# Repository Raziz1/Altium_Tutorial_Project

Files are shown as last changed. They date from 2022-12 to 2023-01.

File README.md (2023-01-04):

# Altium_Tutorial_Project ⚡🖥️
The following files were completed as a part of the Altium free PCB design course. Project A - A Power Regulator and LED Board. The PCB design course can be found at the following link below
* [Altium Education Courses](https://education.altium.com/)

This project goes over all the material covered in this course which includes
* Schematics & Libraries
* PCB Layout
* Routing & Basic Signal Integrity
* PCB Manufacturing

## Functional Requirements



The primary goal of this project was to design a power regulator shield board for the Arduino Uno that powers a bank of LEDs as well as the Arduino Uno. The design of the board had to meet the following set of requirements:

1. Receive power from a 12 V DC input
2. Regulate power down to 5 V DC
3. Deliver 12 V DC power to a bank of 2 LED lights in parallel
4. Provide 5 V DC power to the main Arduino Uno board
5. Provide enough current to power the Arduino and the LEDs
6. Regulate power with at least 90% efficiency
7. LEDs must be SMD parts with high power output (at least 10 W each)
8. Power input connection is provided by standard 16 AWG wire
9. Components must be placed only on the top layer
10. Total board thickness must be standard thickness (approximately 62 mils)

When designing the board shape I referenced the Arduino.cc website [See this link](https://store-usa.arduino.cc/products/arduino-uno-rev3/?selectedStore=us)

## Creating the schematics
When designing the schematics there were a couple components that required external libraries.

| **Part number**  | **Quantity** | **Description** | **Where To Find** |
| --- |:---:|:---:|:---:|
| SSQ-108-03-T-S| 2 | 8-pin header | [Link](https://www.samtec.com/products/ssq-108-03-t-s)| 
| SSQ-106-03-T-S| 1 | 6-pin header | [Link](https://www.samtec.com/products/ssq-106-03-t-s)| 
| SSQ-110-03-T-S| 1 | 10-pin header | [Link](https://www.samtec.com/products/ssq-110-03-t-s)| 

The rest of the parts including the LEDs (MKRAWT-00-0000-0D0HG235H) can be directly placed from the manufacturer's part search.

The power regulator design was made using the [WeBench platform](https://webench.ti.com/power-designer/) with the following requirements:
* Vin Min: 12 V 
* Vin Max: 12 V 
* Vout: 5 V 
* Iout Max: 1 A

This project used the TPS562200 regulator design.

## PCB layout
Details related to the PCB layout & Stackup layout can be found in the output files above

## Output files
The following output files were included
* Bill of Materials
* Gerber
* NC Drill 
* Pick-and-place
* Board Stackup
* Drill Drawing/Guides
* Schematic Prints
* PCB prints

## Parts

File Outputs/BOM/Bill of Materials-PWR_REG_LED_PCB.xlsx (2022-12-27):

Comment | Description | Designator | Footprint | LibRef | Quantity
CC0805KRX7R8BB104 | CAP CER 0.1UF 25V X7R 0805 | Cbst, Cin1, Cin2, Cout1, Cout2 | FP-CC0805-0_85-MFG | CMP-1036-04410-2 | 5
MKRAWT-00-0000-0D0HG235H | LED, White, 12 V, 2-Pin SMD, RoHS, Tape and Reel | D1, D2 | CREE-MK-R-2_V | CMP-2100-00977-1 | 2
8-Pin-Header | 8 Position Receptacle Connector Through Hole, Right Angle | J1, J4 | SAMTEC_SSQ-108-03-X-S | SSQ-108-03-X-S | 2
1x6 Header | 6 Position Receptacle Connector Through Hole | J2 | SAMTEC_SSQ-106-03-X-S | SSQ-106-03-X-S | 1
10-Pin-Header | 10 Position Receptacle Connector Through Hole, Right Angle | J3 | SAMTEC_SSQ-110-03-X-S | SSQ-110-03-X-S | 1
NRS8030T3R3MJGJ | Inductor Power Shielded Wirewound 3.3uH 20% 100KHz Ferrite 4.2A 24.7mΩ DCR T/R | L1 | FP-NRS8030-MFG | CMP-14484-000405-1 | 1
ERJ2RKF1002X | Chip Resistor, 10 KOhm, +/- 1%, 0.1 W, -55 to 155 degC, 0402 (1005 Metric), RoHS, Tape and Reel | Rfbb | RESC1005X40X25LL05T05 | CMP-2000-07588-1 | 1
CRCW020156K2FNED |  | Rfbt | RESC0603X28X15NL05T05 | CMP-2004-00723-1 | 1
TPS562201DDCR | IC REG BUCK ADJ 2A TSOT23-6 | U1 | FP-DDC0006A-IPC_C | CMP-04918-000361-1 | 1

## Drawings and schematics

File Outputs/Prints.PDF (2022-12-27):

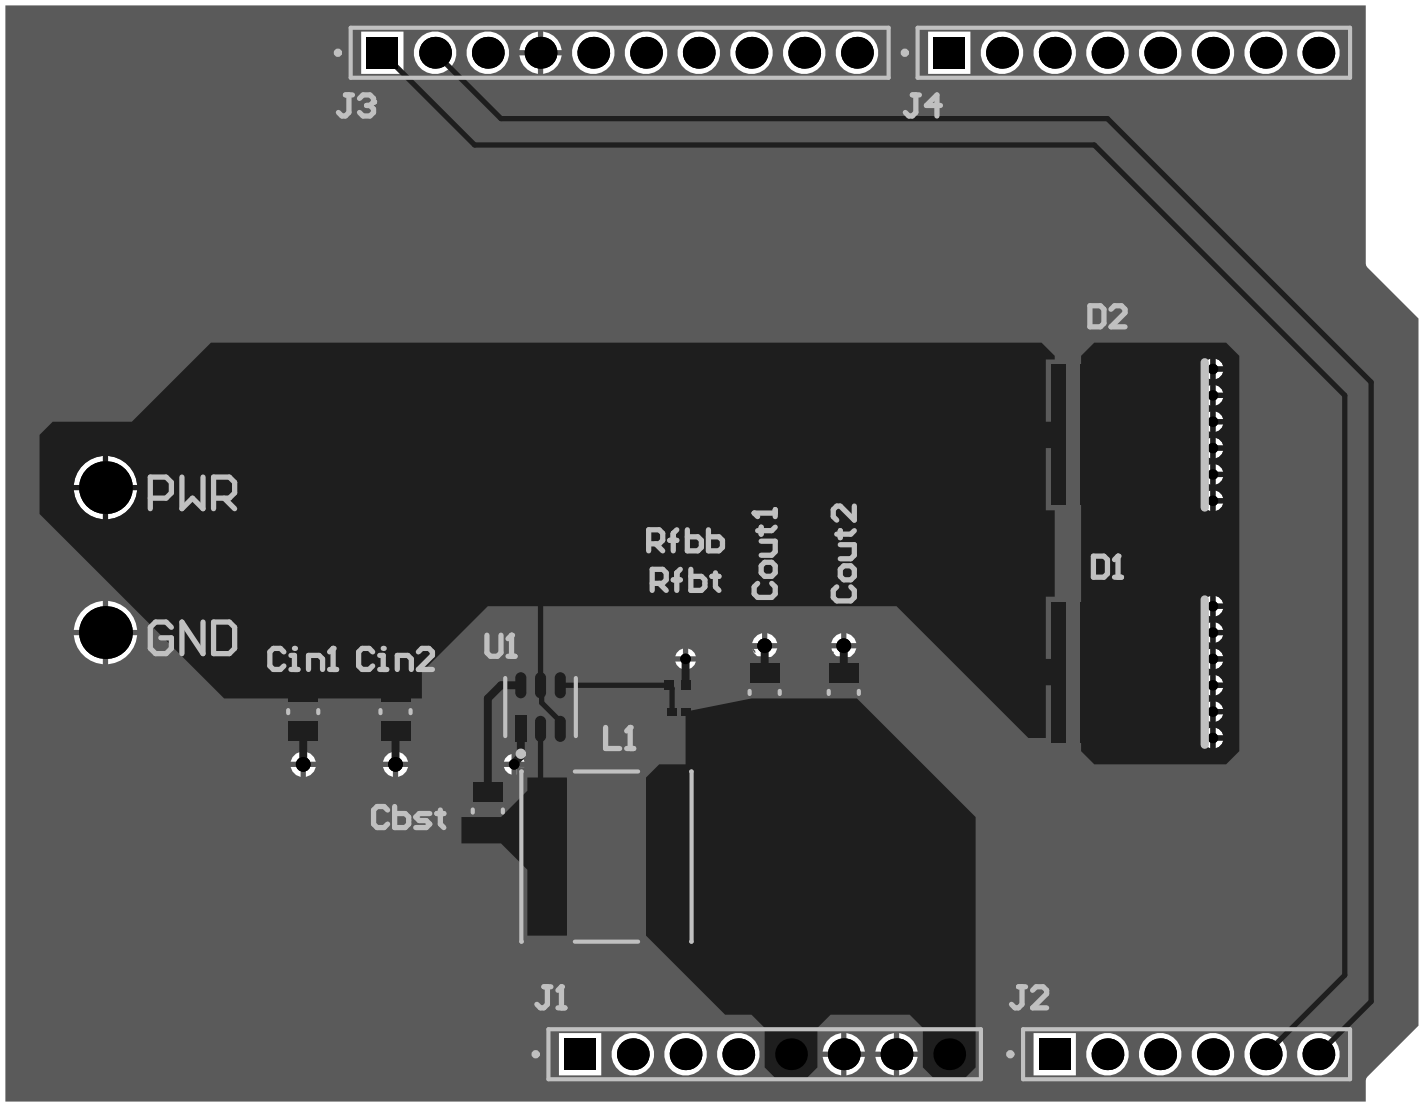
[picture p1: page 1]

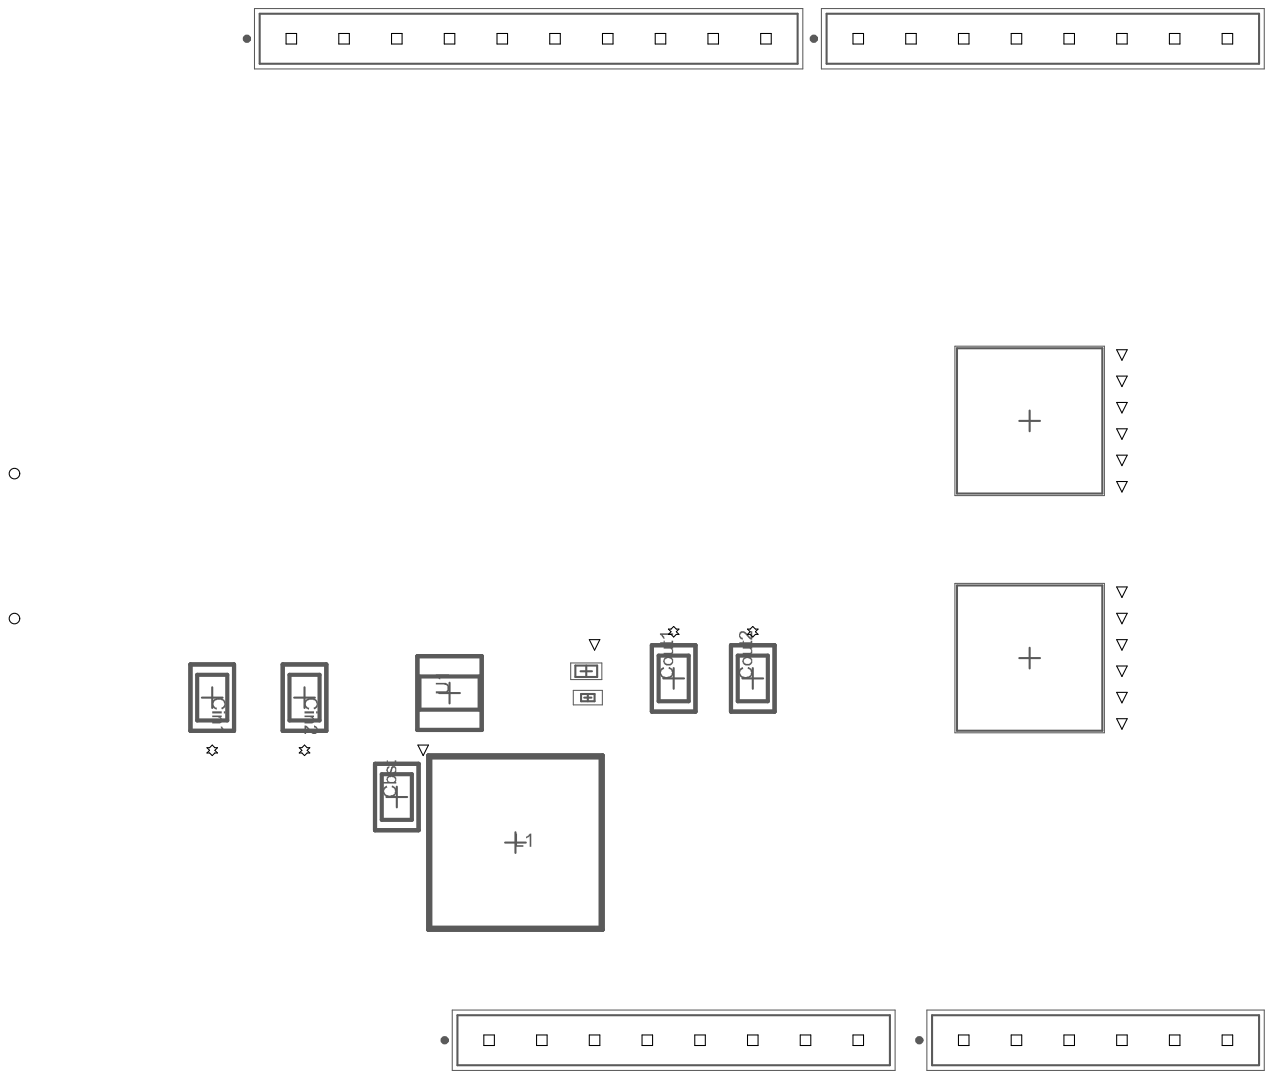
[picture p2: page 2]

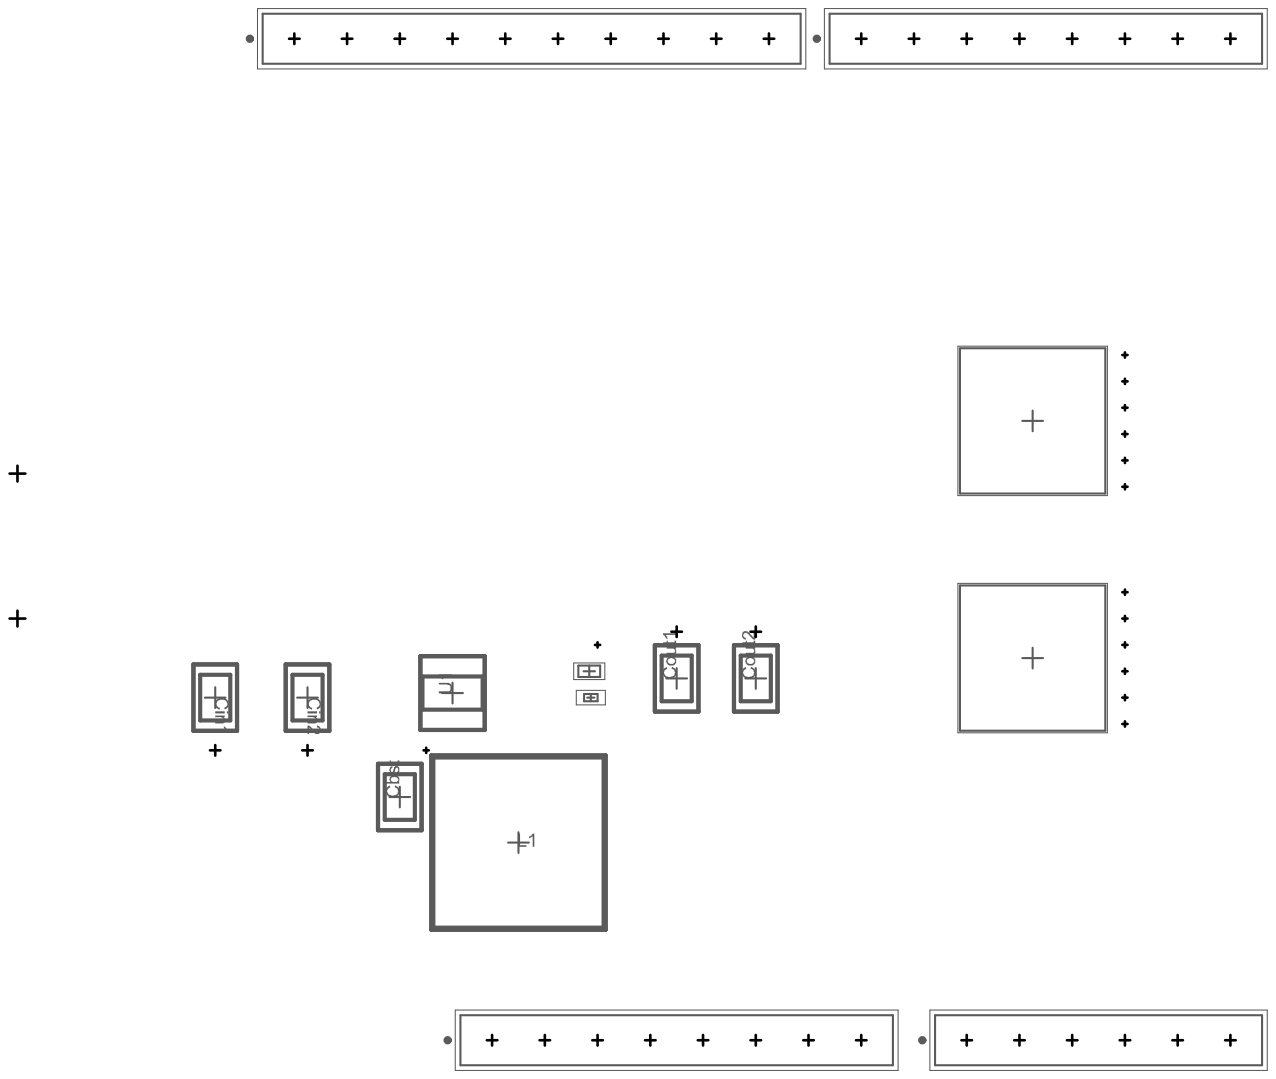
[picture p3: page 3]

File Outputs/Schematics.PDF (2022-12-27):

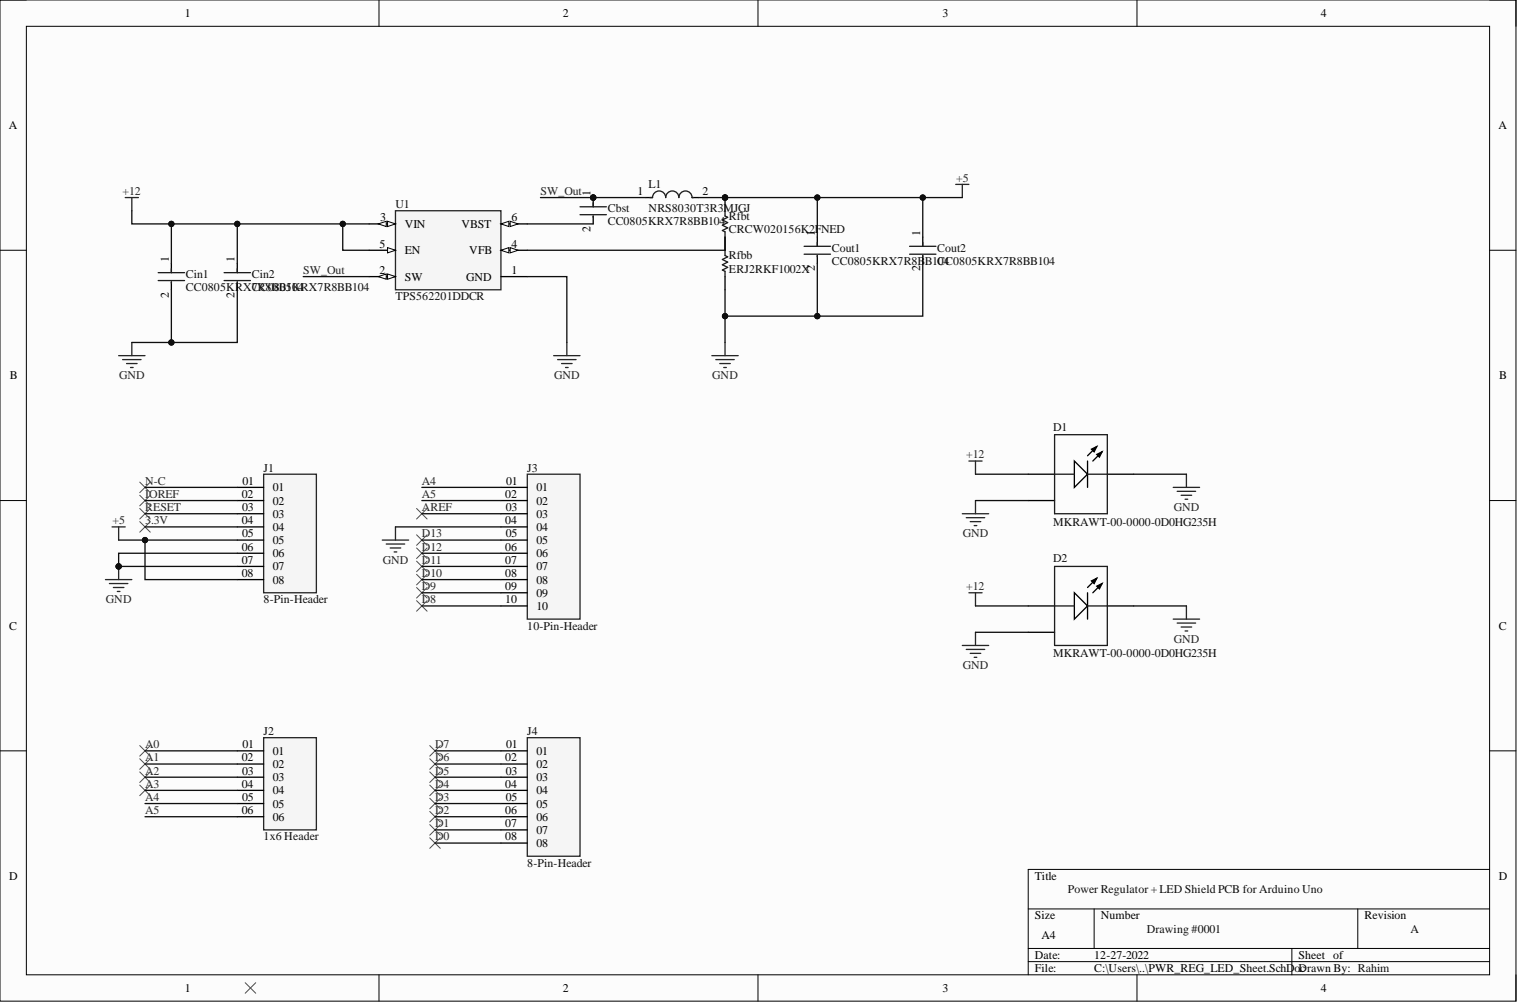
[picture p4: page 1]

0 6
0 7
0 8

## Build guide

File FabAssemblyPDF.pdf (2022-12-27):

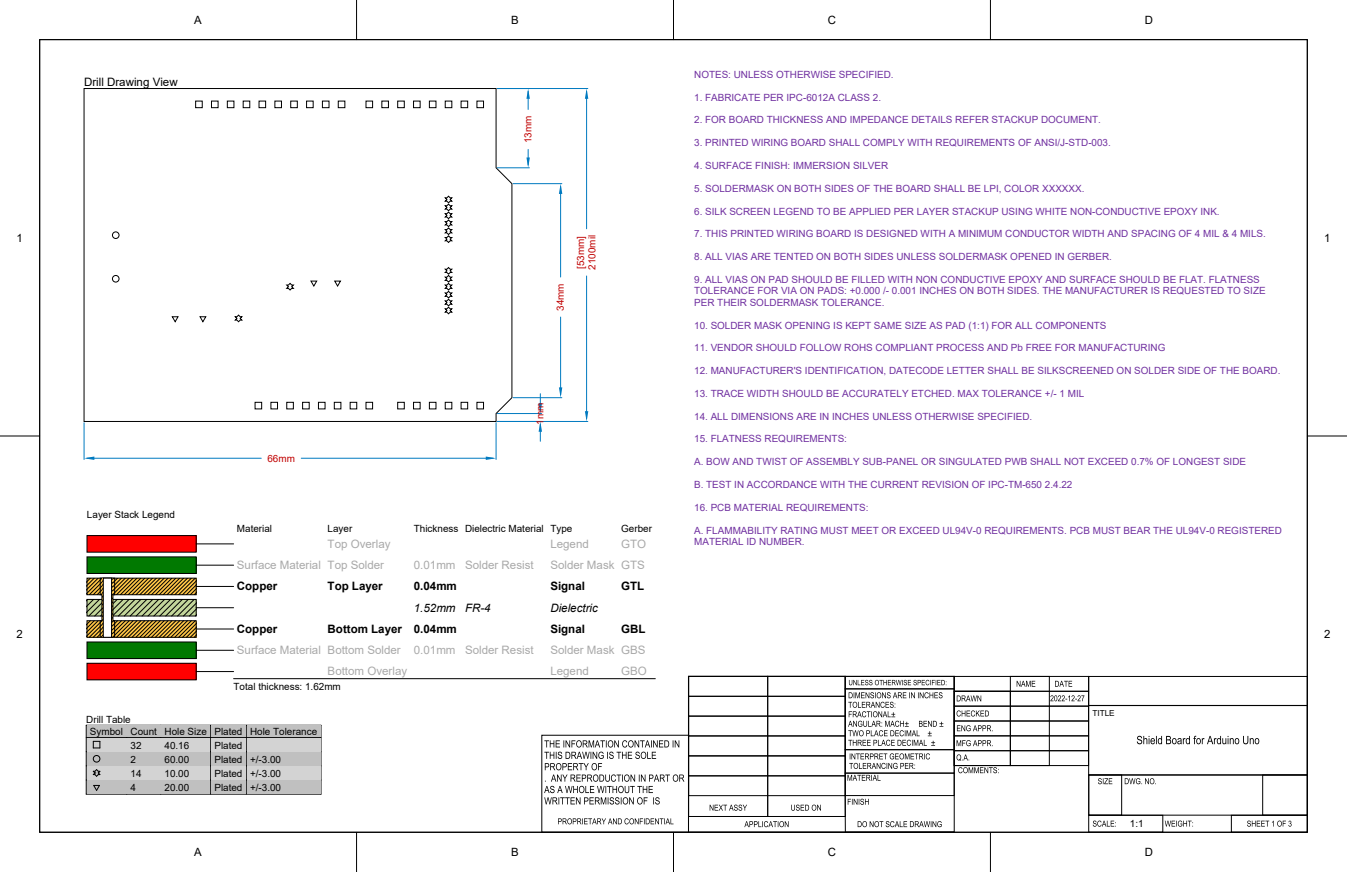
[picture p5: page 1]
Drill Table; TITLE; Material; Layer; Thickness Dielectric Material Type; Gerber; Top Overlay; Legend; GTO; Surface Material Top Solder; 0.01mm Solder Resist; Solder Mask GTS; Copper; Top Layer; Signal; GTL; Dielectric; Bottom Layer 0.04mm; GBL; Surface Material Bottom Solder 0.01mm Solder Resist; Solder Mask GBS; Bottom Overlay; GBO; Total thickness: 1.62mm; 2100mil; 15. FLATNESS REQUIREMENTS:

NOTES: UNLESS OTHERWISE SPECIFIED.

Drill Drawing View

1. FABRICATE PER IPC-6012A CLASS 2.

2. FOR BOARD THICKNESS AND IMPEDANCE DETAILS REFER STACKUP DOCUMENT.

3. PRINTED WIRING BOARD SHALL COMPLY WITH REQUIREMENTS OF ANSI/J-STD-003.

4. SURFACE FINISH: IMMERSION SILVER

5. SOLDERMASK ON BOTH SIDES OF THE BOARD SHALL BE LPI, COLOR XXXXXX.

6. SILK SCREEN LEGEND TO BE APPLIED PER LAYER STACKUP USING WHITE NON-CONDUCTIVE EPOXY INK.

7. THIS PRINTED WIRING BOARD IS DESIGNED WITH A MINIMUM CONDUCTOR WIDTH AND SPACING OF 4 MIL & 4 MILS.

8. ALL VIAS ARE TENTED ON BOTH SIDES UNLESS SOLDERMASK OPENED IN GERBER.

9. ALL VIAS ON PAD SHOULD BE FILLED WITH NON CONDUCTIVE EPOXY AND SURFACE SHOULD BE FLAT. FLATNESS
TOLERANCE FOR VIA ON PADS: +0.000 /- 0.001 INCHES ON BOTH SIDES. THE MANUFACTURER IS REQUESTED TO SIZE
PER THEIR SOLDERMASK TOLERANCE.

10. SOLDER MASK OPENING IS KEPT SAME SIZE AS PAD (1:1) FOR ALL COMPONENTS

11. VENDOR SHOULD FOLLOW ROHS COMPLIANT PROCESS AND Pb FREE FOR MANUFACTURING

12. MANUFACTURER'S IDENTIFICATION, DATECODE LETTER SHALL BE SILKSCREENED ON SOLDER SIDE OF THE BOARD.

13. TRACE WIDTH SHOULD BE ACCURATELY ETCHED. MAX TOLERANCE +/- 1 MIL

14. ALL DIMENSIONS ARE IN INCHES UNLESS OTHERWISE SPECIFIED.

A. BOW AND TWIST OF ASSEMBLY SUB-PANEL OR SINGULATED PWB SHALL NOT EXCEED 0.7% OF LONGEST SIDE

B. TEST IN ACCORDANCE WITH THE CURRENT REVISION OF IPC-TM-650 2.4.22

16. PCB MATERIAL REQUIREMENTS:

Layer Stack Legend

A. FLAMMABILITY RATING MUST MEET OR EXCEED UL94V-0 REQUIREMENTS. PCB MUST BEAR THE UL94V-0 REGISTERED
MATERIAL ID NUMBER.

Symbol | Count | Hole Size | Plated | Hole Tolerance

32 | 40.16 | Plated
2 | 60.00 | Plated | +/-3.00
14 | 10.00 | Plated | +/-3.00
4 | 20.00 | Plated | +/-3.00

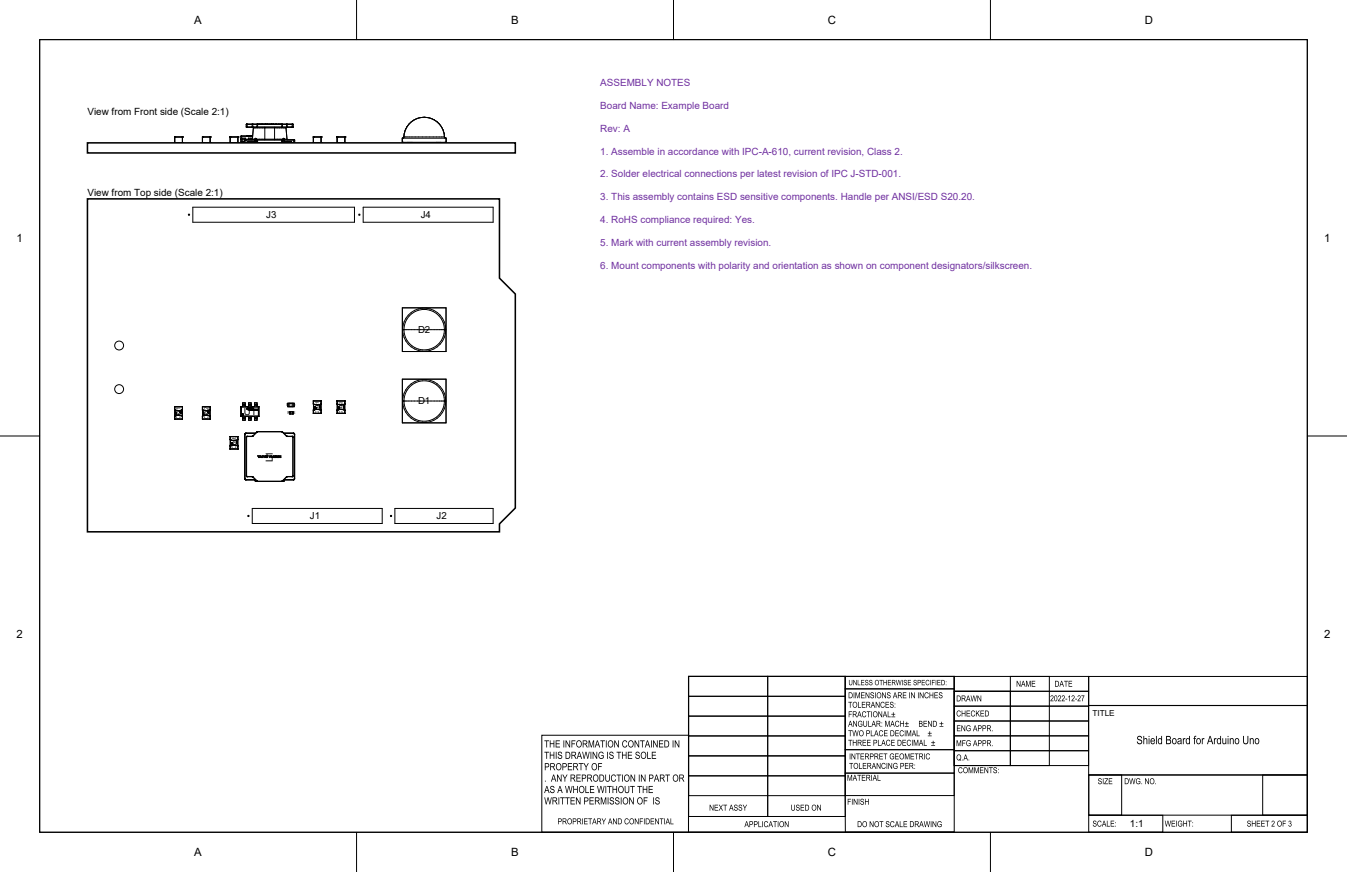
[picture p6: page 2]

Board Name: Example Board

View from Front side (Scale 2:1)

1. Assemble in accordance with IPC-A-610, current revision, Class 2.

2. Solder electrical connections per latest revision of IPC J-STD-001.

View from Top side (Scale 2:1)

3. This assembly contains ESD sensitive components. Handle per ANSI/ESD S20.20.

4. RoHS compliance required: Yes.

5. Mark with current assembly revision.

6. Mount components with polarity and orientation as shown on component designators/silkscreen.

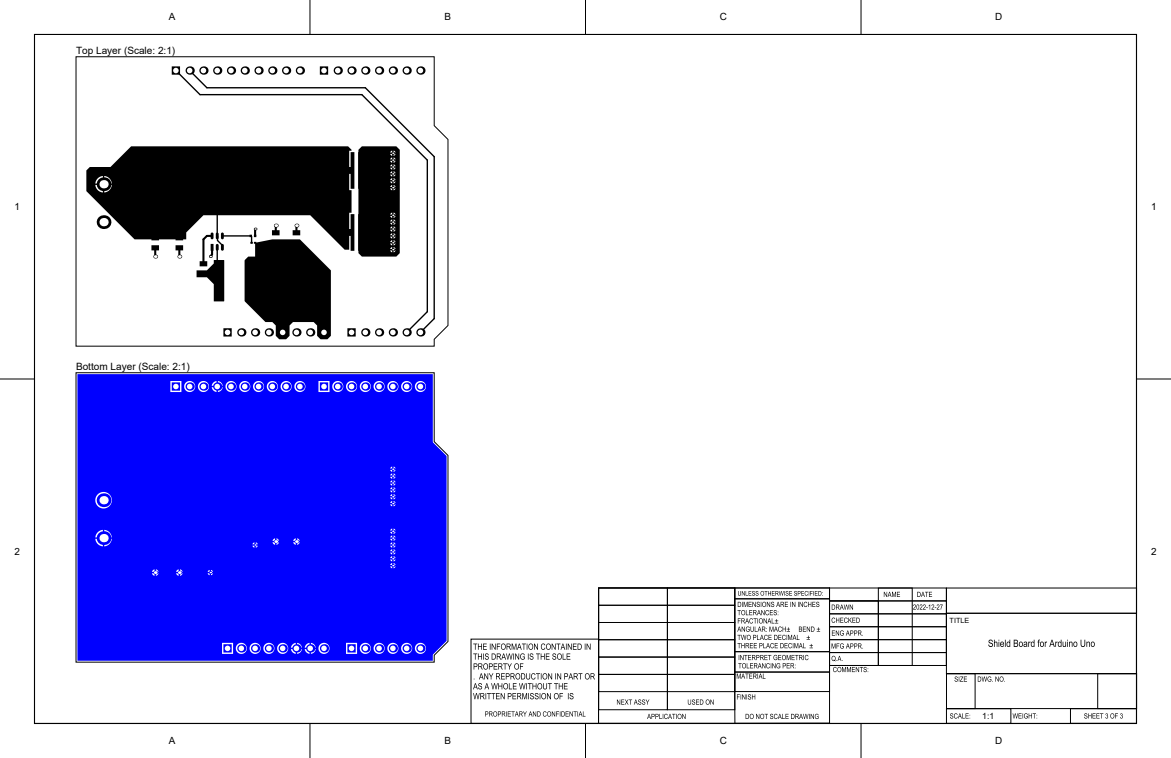
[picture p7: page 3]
TITLE

Top Layer (Scale: 2:1)

Bottom Layer (Scale: 2:1)
